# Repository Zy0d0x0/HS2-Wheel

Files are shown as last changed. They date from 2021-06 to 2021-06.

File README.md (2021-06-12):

# HS2/Hid-Wheel

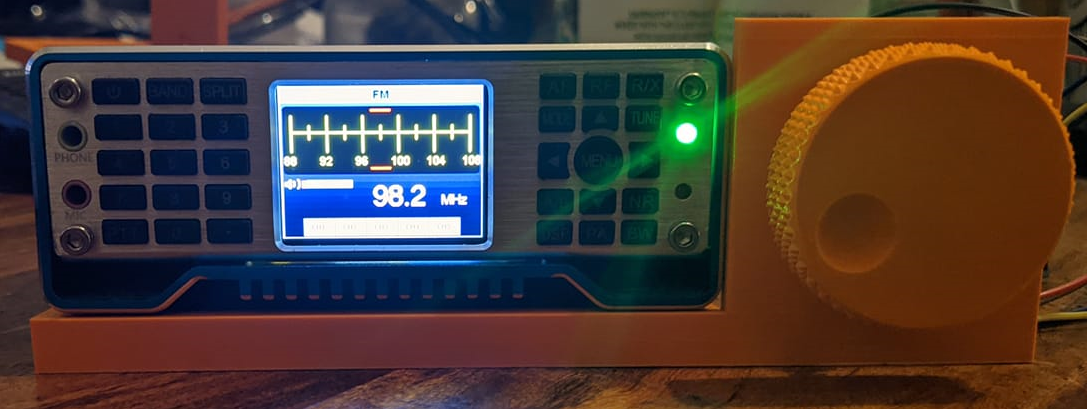
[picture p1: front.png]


Since the new release of the HS2 Firmware version V1.3.7. It was noted in the changelog that USB support 
has been added to the radio using the port on the rear. This gave M7SYN a idea to use a Ardunio to
simulate a USB keyboard to work as a tuner and navigational wheel. The below project shows how M7SYN created
this little wheel that should of been added to the HS2 or created as sub product sold along with the radio inculded
with the price.

# Credits

* Thanks to both SQ9CWN & EI8FIB for helping find out the keys used by the keyboard as M7SYN does not own a wired USB keyboard.
* Editing & proof-reading done by M7GCH.

Keys found to be in use with keybord control:

Keyboard Key | Function
-------------- | -------------
F2 |Band
F3 |BW
F4 |RF - RF Gain setting
F5 |RF - IF Gain setting
F6 |Mode
F7 |Spec Menu
F8 |AF
F9 |Menu short press - enter option in menu
F10 |Menu long press - enter main menu, exit  from menu option
Page Up |cursor/option right
Page Down |cursor/option left

# Hardware Setup

Required Hardware:

* Ardunio Uno - atmega16u2-Uno-Rev3
* Rotary Encoder
* Wires
* 3D Printer

The wiring for this wheel is simple as it's just a rotary encoder connected to the Ardunio.

M7SYN just connects the wires directly to the encoder for this project.



The below table shows the Pin Connections between the Encoder and the Ardunio:

Rotary Encoder | Ardunio Pins
-------------- | -------------
GRD | GRD
5V | 5V
SW | DPin 4
DT | DPin 3
CLK | DPin 2

Resource From: https://lastminuteengineers.com/rotary-encoder-arduino-tutorial/

Using a 3D printer it is possible to print the following frame for the rotary encoder to then next be screwed into
and when a tuner knob has either been used from this git or has been sourced on other resourses this can be applied. 
 
When fitting the rotary encoder to the frame it maybe found that the fitment is tight as in this project the washer was not used. 
It was also found by bending the little tab on the encoder it allowed the locking nut to fit over the top and be tighted up.

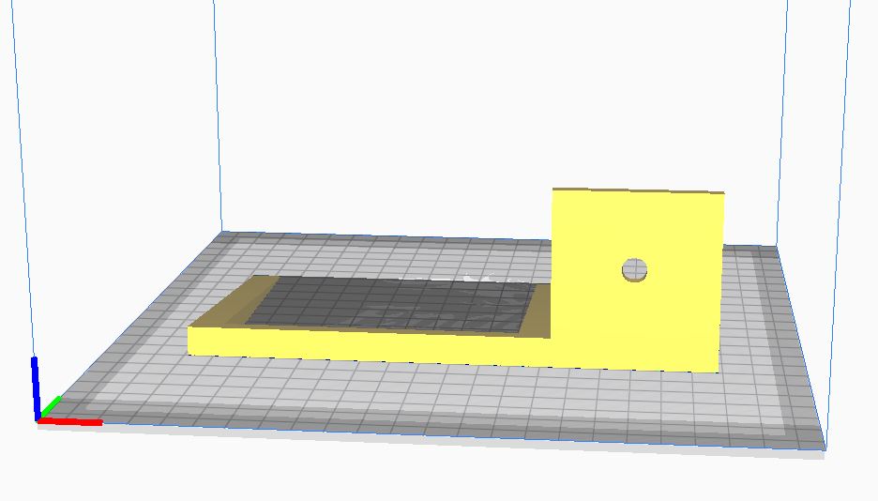
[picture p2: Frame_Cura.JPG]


The Knob can be found here https://www.thingiverse.com/thing:2797118

# Software Setup

Download and Install Flip https://www.microchip.com/Developmenttools/ProductDetails/FLIP
This will later be used to flash the ardunio with a new firmware so when the Ardunio is 
plugged into any device it should then load as USB Keyboard.

Connect the Ardunio and open up Device Manager, take note the Ardunio is currently
displaying as a COM port. While the Ardunio is currently connected and showing as a COM port
the `Main-Wheel.ino` needs to be put onto the Ardunio using what ever IDE you normaly use.

When the Ardunio has the `Main-Wheel.ino` sketch copied to its onboard memory. The Ardunio then needs 
to put into DFU mode this can by done by using a jumper pin or a small peice of wire
and shorting the 2 pins shown in the below image. 

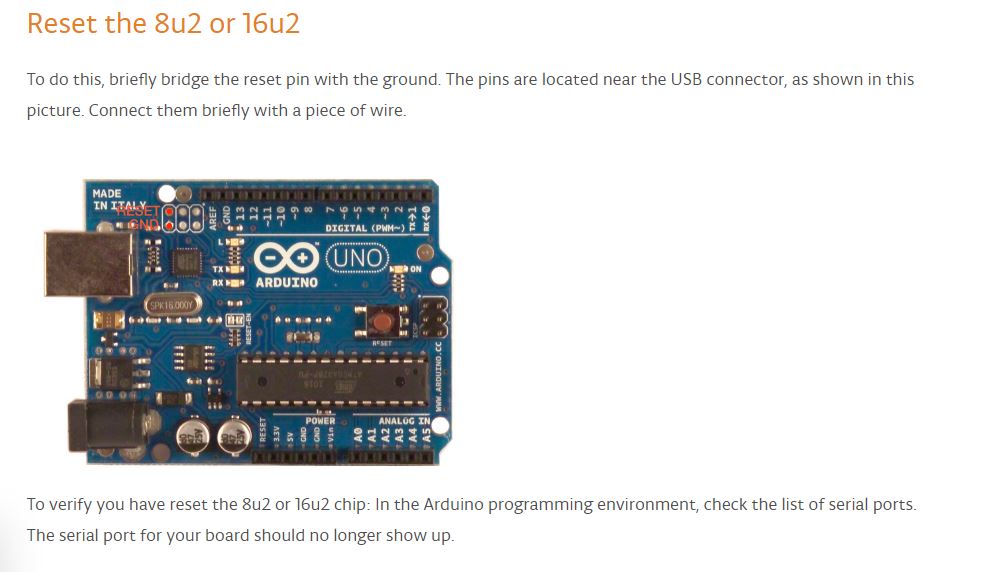
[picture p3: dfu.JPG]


Resource from: https://www.arduino.cc/en/Hacking/DFUProgramming8U2

As displayed in the above screenshot when the pins have been shorted take another look at device manager it should
noted the Ardunio is not longer showing as a COM port and it may be missing its driver, If this is the case right click and then click update driver, 
select install driver from a local folder on the computer then navigate to `C:\Program Files (x86)\Atmel\Flip 3.4.7\usb`
then click update driver this should now install the required driver for Ardunio DFU mode so that FLIP can connect to it.

Open the FLIP tool and click on the button that looks like a micro chip and select ATmega16U2 in the dropdown menu then click the ok button to save the changes.

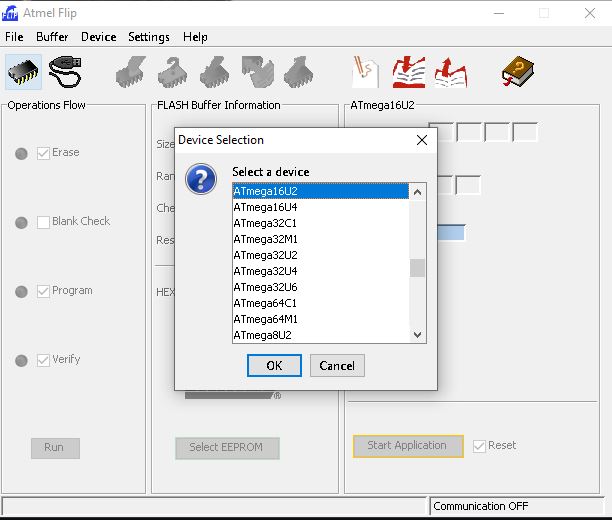
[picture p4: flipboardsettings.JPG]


Once the settings have been set for the Ardunio click the `Connect` Button. This is next to the micro chip button prevoisuly pressed. Once the `Connect` button has been press you should see a `USB` button that also needs to be clicked. It should be noticed at the bottom of the FLIP software
the connection will then become established. 

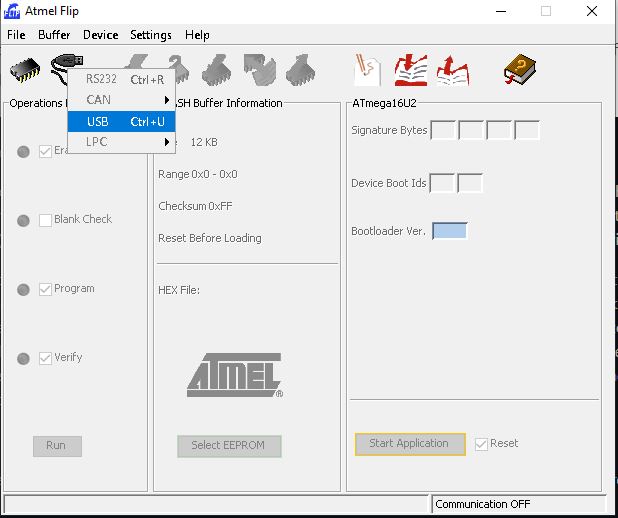
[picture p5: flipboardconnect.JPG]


By clicking the `File` button and `Load HEX File`, Select the `Arduino-keyboard-0.3.hex` file and click then `Run` button on the lower part of the applications. Once this has comleted click the `Start Application` button you should then hear the Ardunio disconnect. Un-plug the Ardunio and plug it back in again to power cycle it.
Now it should be possible to see in device manager the device does not display as a COM port.
Open up notepad add some text then try using the wheel to navigate if all goes well on windows try pluggin in the wheel into the HS2 usb port on the rear of the radio.

The primay resource for the flashing of the Arduino to make it aa keybord was found by watching this video: https://www.youtube.com/watch?v=tvqA-JcTQNg

# Restoring The Ardunio

Returning the Ardunio to its normal state is possible by putting the ardunio into DFU mode once again with the jumper pin
then instead of selecting the `Arduino-keyboard-0.3.hex` file this time around you need to use the `Arduino-usbserial-atmega16u2-Uno-Rev3.hex`.

# Todo

- [ ] Create rear cover to enclose the Ardunio while still exposing the USB port.

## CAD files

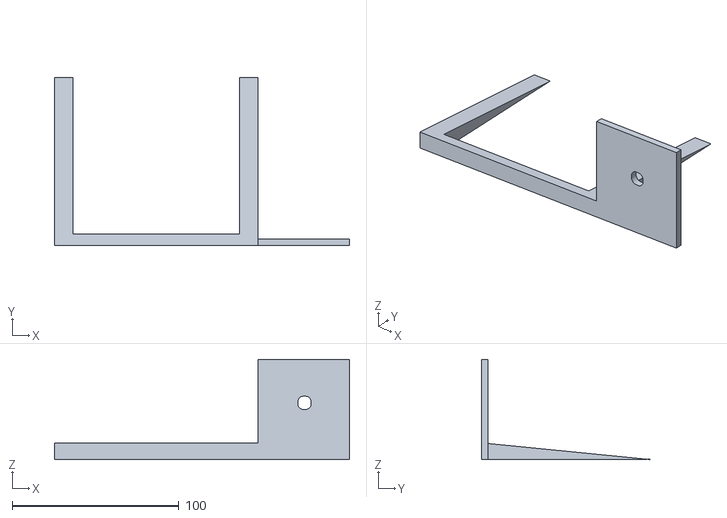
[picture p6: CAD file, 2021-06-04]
Frame.stl
177.0 x 101.0 x 60.0

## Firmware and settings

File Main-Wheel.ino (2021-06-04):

// Rotary Encoder Inputs
#define CLK 2
#define DT 3
#define SW 4

 uint8_t buf[8] = {
  0
}; 

int counter = 0;
int currentStateCLK;
int lastStateCLK;
String currentDir ="";
unsigned long lastButtonPress = 0;


boolean Flip1State = false;
boolean Flip2State = false;

boolean buttonActive = false;
boolean longPressActive = false;

long buttonTimer = 0;
long longPressTime = 400;


int upLeft = 79;
int downRight = 80;


void setup() {
  
  // Set encoder pins as inputs
  pinMode(CLK,INPUT);
  pinMode(DT,INPUT);
  pinMode(SW, INPUT_PULLUP);

  // Setup Serial Monitor
  Serial.begin(9600);

  // Read the initial state of CLK
  lastStateCLK = digitalRead(CLK);
}

void loop() {
  
  // Read the current state of CLK
  currentStateCLK = digitalRead(CLK);

  // If last and current state of CLK are different, then pulse occurred
  // React to only 1 state change to avoid double count
  if (currentStateCLK != lastStateCLK  && currentStateCLK == 1){

    // If the DT state is different than the CLK state then
    // the encoder is rotating CCW so decrement
    if (digitalRead(DT) != currentStateCLK) {
      counter --;
      currentDir ="CCW";
      buf[2] = upLeft; 
      Serial.write(buf, 8);
      releaseKey();
    } else {
      // Encoder is rotating CW so increment
      counter ++;
      currentDir ="CW";
      buf[2] = downRight; 
      Serial.write(buf, 8);
      releaseKey();
    }

  }

  // Remember last CLK state
  lastStateCLK = currentStateCLK;

  // Read the button state
  int btnState = digitalRead(SW);

  //If we detect LOW signal, button is pressed
  if (btnState == LOW) {
   if (buttonActive == false) {
      buttonActive = true;
      buttonTimer = millis();
    }

    if ((millis() - buttonTimer > longPressTime) && (longPressActive == false)) {

      longPressActive = true;
      Flip1State = !Flip1State;

      if (Flip1State == 1){
        upLeft = 79;
        downRight = 80;
        
      } else {
        upLeft = 82;
        downRight = 81;
      }
     
    } 
  
  } else {
    if (buttonActive == true) {

      if (longPressActive == true) {
        longPressActive = false;

      } else {
        Flip2State = !Flip2State;
        buf[2] = 40;    // HID: ENTER key
        Serial.write(buf, 8);
        releaseKey();  
      }

      buttonActive = false;
     
    }
 
  }

  // Put in a slight delay to help debounce the reading
  delay(1);
}

void releaseKey()
{
  buf[0] = 0;
  buf[2] = 0;
  Serial.write(buf, 8); // Release key
}

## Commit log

2021-05-31 Ardunio code for USB Keyboard commands
    This is a ardunio sketch to tell the radio what keyboard buttons have been pressed when the wheel is moved or clicked.
2021-05-31 Frame to be 3d printed by the user
    [frame.stl]
2021-06-01 Rename Wheel.-Do-Not-Use-Me-Im-Oval.ino to Main-Wheel.ino
    Dont drink beer when renaming files.
2021-06-04 Long press now switches the buttons over
    When a user now long presses the encoder button it will switch between up and down. if the user then long presses the button once again
    it will return to the normal state. If the button is just single clicked it will press the enter button.
